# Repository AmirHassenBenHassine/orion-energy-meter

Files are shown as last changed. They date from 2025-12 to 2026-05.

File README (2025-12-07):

 # Orion Energy Monitor

A three-phase energy monitoring system built on ESP32 for real-time power consumption tracking and reporting.

## Overview

The Orion Energy Monitor measures voltage and current across three phases, calculates power consumption, and transmits data via MQTT. It supports WiFi provisioning through a captive portal, OTA firmware updates, and battery-powered operation with light sleep for power efficiency.

## Hardware Requirements

- ESP32 development board
- ZMPT101B voltage sensor module
- 3x SCT-013 current transformer sensors 
- Li-ion battery with charging circuit 
- Status LEDs (power, WiFi, charging, battery)
- Push buttons for WiFi pairing and hard reset

## Pin Configuration

| Function | GPIO |
|---|---|
| Voltage Sensor | 32 |
| Current Phase R | 39 |
| Current Phase Y | 34 |
| Current Phase B | 35 |
| Battery Voltage | 36 |
| Power LED | 14 |
| WiFi LED | 27 |
| Charging LED | 26 |
| Battery LED | 25 |
| WiFi Pairing Button | 4 |
| Hard Reset Button | 13 |
| Charging Status | 33 |

## Features

### Energy Monitoring
- Three-phase voltage and current measurement
- Real-time power calculation per phase
- Cumulative energy tracking (kWh)
- Configurable calibration values

### Connectivity
- WiFi with captive portal for initial setup
- MQTT for data transmission
- mDNS service discovery for broker detection
- Automatic reconnection handling

### Power Management
- Light sleep between measurement cycles
- Battery voltage monitoring
- Charging status detection
- LED indicators for system status

### Firmware Updates
- OTA updates from GitHub releases
- ETag-based update detection
- Rollback protection

## Building

### Prerequisites

- PlatformIO CLI or IDE
- ESP32 board support

### Build Commands

```bash
# Build firmware
pio run -e esp32dev

# Upload to device
pio run -t upload -e esp32dev

# Monitor serial output
pio device monitor
```

## Configuration

Edit `include/config.h` to modify:

- `DATA_SEND_INTERVAL_MS` - Interval between measurements (default: 30000ms)
- `MQTT_BROKER_HOST` - MQTT broker hostname
- `MQTT_BROKER_PORT` - MQTT broker port (default: 1883)
- `VOLTAGE_CALIBRATION` - Voltage sensor calibration factor
- `CURRENT_CALIBRATION_DEFAULT` - Current sensor calibration factor

## MQTT Topics

| Topic | Direction | Description |
|---|---|---|
| `energy/metrics` | Publish | JSON payload with energy data |
| `orion/status` | Publish | Device connection status |
| `orion/config` | Subscribe | WiFi credential updates |
| `orion/trigger` | Subscribe | Remote commands |
| `orion/refresh` | Subscribe | Network scan requests |

### Metrics Payload Format

```json
{
  "deviceId": "XXXXXXXXXXXX",
  "battery": 85.5,
  "timestamp": "2025-01-15 14:30:00",
  "voltage": 230.5,
  "totalPower": 1500.0,
  "energyTotal": 12.5,
  "phases": [
    {"current": 2.1, "power": 483.0},
    {"current": 2.3, "power": 529.0},
    {"current": 2.1, "power": 488.0}
  ]
}
```

## WiFi Provisioning

1. Hold the WiFi pairing button during boot
2. Connect to the "OrionSetup" access point
3. Configure WiFi credentials through the captive portal
4. Device will restart and connect to the configured network

## Hard Reset

Hold the hard reset button during boot to erase all stored credentials and settings. The device will restart in provisioning mode.

## MQTT Broker Setup

The device uses mDNS to discover MQTT brokers. For automatic discovery, configure your broker to advertise via mDNS:

### Mosquitto on Linux

Create `/etc/avahi/services/mosquitto.service`:

```xml
<?xml version="1.0" standalone='no'?>
<!DOCTYPE service-group SYSTEM "avahi-service.dtd">
<service-group>
  <name>Mosquitto MQTT Broker</name>
  <service>
    <type>_mqtt._tcp</type>
    <port>1883</port>
  </service>
</service-group>
```

Restart Avahi:

```bash
sudo systemctl restart avahi-daemon
```

## Calibration

### Voltage Calibration

1. Measure actual mains voltage with a multimeter
2. Compare with reported voltage
3. Adjust `VOLTAGE_CALIBRATION` in config.h:
   ```
   new_cal = current_cal * (actual_voltage / reported_voltage)
   ```

### Current Calibration

1. Connect a known load
2. Measure actual current with a clamp meter
3. Adjust `CURRENT_CALIBRATION_DEFAULT` similarly

## Project Structure

```
orion_monitor/
├── include/
│   ├── config.h           # Configuration constants
│   ├── battery_manager.h
│   ├── ble_manager.h
│   ├── button_manager.h
│   ├── energy_sensor.h
│   ├── led_manager.h
│   ├── mqtt_manager.h
│   ├── ota_manager.h
│   ├── utils.h
│   └── wifi_manager.h
├── src/
│   ├── main.cpp           # Application entry point
│   ├── battery_manager.cpp
│   ├── ble_manager.cpp
│   ├── button_manager.cpp
│   ├── energy_sensor.cpp
│   ├── led_manager.cpp
│   ├── mqtt_manager.cpp
│   ├── ota_manager.cpp
│   ├── utils.cpp
│   └── wifi_manager.cpp
├── platformio.ini         # Build configuration
└── README.md
```

## Dependencies

Managed automatically by PlatformIO:

- WiFiManager
- PubSubClient
- ArduinoJson
- EmonLib
- NimBLE-Arduino

## Troubleshooting

### Device not connecting to WiFi
- Verify credentials are correct
- Check signal strength
- Try moving closer to the access point
- Use hard reset to clear stored credentials

### MQTT connection failing
- Verify broker is running and accessible
- Check firewall settings
- Ensure mDNS/Avahi is configured on broker host
- Check broker logs for connection attempts

### Incorrect readings
- Verify sensor connections
- Check calibration values
- Ensure CT sensors are oriented correctly on the wire
- Confirm voltage sensor is connected to live and neutral

### High power consumption
- Reduce `DATA_SEND_INTERVAL_MS` 
- Check for floating GPIO pins

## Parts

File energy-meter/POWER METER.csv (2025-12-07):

Qty | Value | Device | Package | Parts | Description | AVAILABILITY | CHECK_PRICES | COMMENT | CONFIGURATION_POLE-THROW | CONTACT_CURRENT_RATING | DESCRIPTION | MF | MP | MPN | OC_FARNELL | OC_NEWARK | PACKAGE | POPULARITY | PRICE | SNAPEDA_LINK | SPICEMODEL | SPICEPREFIX
2 |  | AK500/2 | AK500/2 | X1, X2 | CONNECTOR |  | https://cothings.net/collections/pins/products/bornier-a-visser-2-poles |  |  |  |  |  |  |  | unknown | unknown |  | 14
2 |  | C-EUC1206K | C1206K | C5, C6 | CAPACITOR, European symbol |  |  |  |  |  |  |  |  |  |  |  |  | 13 |  |  |  | C
4 |  | CPOL-EUE2.5-6 | E2,5-6 | C2, C3, C4, C7 | POLARIZED CAPACITOR, European symbol |  |  |  |  |  |  |  |  |  |  |  |  | 26 |  |  |  | C
4 |  | LEDCHIPLED_1206 | CHIPLED_1206 | CHARGED, CHARGING, POWER, WIFI | LED |  | https://2btrading.tn/afficheurs-led-lcd/5230-diode-led-smd-1206-orange.html |  |  |  |  |  |  |  |  |  |  | 28
6 |  | PINHD-1X1 | 1X01 | JP11, JP14, JP15, JP16, JP17, JP18 | PIN HEADER |  |  |  |  |  |  |  |  |  |  |  |  | 64
1 |  | PINHD-1X4 | 1X04 | JP2 | PIN HEADER |  |  |  |  |  |  |  |  |  |  |  |  | 91
1 |  | PINHD-1X6/90 | 1X06/90 | JP1 | PIN HEADER |  | https://cothings.net/collections/pins/products/barrette-secable-femelle-40pin-2-54mm |  |  |  |  |  |  |  |  |  |  | 10
6 | 634 | RR1206 | R1206 | R7, R8, R9, R10, R13, R14 | RESISTOR, European symbol |  |  |  |  |  |  |  |  |  |  |  |  |  |  |  | NONE | R
1 |  | S02P | S02P | ON/OFF | AMP MT CONNECTOR |  | https://www.celectronix.com/ensembles-c-bles/5455-connecteur-2p-jst-xh-male-2-54mm.html |  |  |  |  |  |  |  | unknown | unknown |  | 0
1 |  | S04P | S04P | SV2 | AMP MT CONNECTOR |  | https://www.celectronix.com/ensembles-c-bles/5453-connecteur-4p-jst-xh-male-2-54mm.html |  |  |  |  |  |  |  | unknown | unknown |  | 0
12 | 10k | RR1206 | R1206 | R1, R2, R3, R4, R5, R6, R11, R12, R15, R16, R17, R18 | RESISTOR, European symbol |  |  |  |  |  |  |  |  |  |  |  |  |  |  |  | NONE | R
4 | 1437566-3 | 1437566-3 | SW_1437566-3 | BOOT, EN, RESET2, RESET3 | Switch Tactile OFF (ON) SPST Rectangular Button Gull Wing 0.05A 12VDC SMD Loose Piece Check availability | In Stock | https://2btrading.tn/commutateurs/6583-bouton-poussoir-3x6x25-flat.html | 1437566-3 | Single Pole - Single Throw | 50 mA | FSMSM=3.5X6 SMT TACT | TE Connectivity 1437566-3 | TE Connectivity | 1437566-3 |  |  |  | None |  | None | https://www.snapeda.com/parts/1437566-3/TE+Connectivity+ALCOSWITCH+Switches/view-part/?ref=snap
1 | AMS1117-3.3 | AMS1117-3.3 | SOT229P700X180-4N | U3 | Check availability | Not in stock | https://cothings.net/products/regulateur-de-tension-ams1117-cms-3-3-v-800-ma |  |  |  | Sot223/Pkg 1-Amp 3.3-Volt Low Drop Out Voltage Regulatator | Advanced Monolithic Systems | AMS1117-3.3 |  |  |  | SOT-223 Seeed Technology |  | None | https://www.snapeda.com/parts/AMS1117-3.3/Advanced+Monolithic+Systems/view-part/?ref=snap
1 | BH-18650-PC | BH-18650-PC | BAT_BH-18650-PC | BT2 | Check availability | In Stock | https://cothings.net/products/support-de-cellule-pour-1x-18650 |  |  |  | Battery Holder (Open) 18650 1 Cell PC Pin | MPD (Memory | BH-18650-PC |  |  |  | None |  | None | https://www.snapeda.com/parts/BH-18650-PC/MPD+%2528Memory+Protection+Devices%2529/view-part/
1 | ESP32-WROOM-32D | ESP32-WROOM-32D | MODULE_ESP32-WROOM-32D | U1 | Bluetooth, WiFi 802.11b/g/n, Bluetooth v4.2 + EDR, Class 1, 2 and 3 Transceiver Module 2.4GHz ~ 2.5GHz Integrated, Trace Surface Mount Check availability | In Stock |  |  |  |  | Bluetooth, WiFi 802.11b/g/n, Bluetooth v4.2 +EDR, Class 1, 2 and 3 Transceiver Module 2.4GHz ~ 2.5GHz Integrated | Espressif Systems | ESP32-WROOM-32D |  |  |  | Non Standard Espressif Systems |  | None | https://www.snapeda.com/parts/ESP32-WROOM-32D/Espressif+Systems/view-part/?ref=snap
3 | SJ2-3573A2-SMT-TR | SJ2-3573A2-SMT-TR | CUI_SJ2-3573A2-SMT-TR | J1, J2, J3 | Check availability | In Stock | https://cothings.net/products/prise-casque-audio-stereo-5-broches-3-5mm-montage-sur-panneau-pcb-pj-324m |  |  |  | 3 conductors, 3.5mm, SMT Audio Jack | Same Sky | SJ2-3573A2-SMT-TR |  |  |  | None |  | None | https://www.snapeda.com/parts/SJ2-3573A2-SMT-TR/Same+Sky/view-part/?ref=snap

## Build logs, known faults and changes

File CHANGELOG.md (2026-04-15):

# Orion Energy Meter — Changelog

All notable changes to the ESP32 energy meter firmware are documented here.
Format follows [Keep a Changelog](https://keepachangelog.com/).

## [1.0.0] — 2026-04-15

### Core Features
- Three-phase energy monitoring (ZMPT101B voltage + 3× SCT-013 current)
- Per-phase NVS-based dynamic calibration with individual R/Y/B values
- Real-time power (W), energy (kWh), and cumulative energy tracking
- CT sensor auto-detection with periodic recheck during operation
- 500-sample RMS voltage measurement for ±1% accuracy

### Connectivity
- WiFi with WPA2 and captive portal provisioning ("OrionSetup" AP)
- MQTT QoS 1 via PubSubClient with mDNS broker auto-discovery
- Automatic MQTT reconnection with exponential backoff
- Smart fallback mode: disables auto-reconnect after prolonged disconnection, switches to manual retry intervals
- WiFi credential updates received over MQTT (orion/config topic)
- mDNS hostname registration as "OrionEM"

### Data Resilience
- NVS-based offline data buffer (672 readings = 1 week at 15-min intervals)
- CompactReading struct (packed binary) for efficient NVS storage
- Automatic buffer flush on MQTT reconnection with progress logging
- Corrupted reading detection and skip during buffer replay
- Ring buffer with separate read/write indices and count metadata

### Power Management
- Light sleep between measurement cycles with configurable duration
- Smart sleep with periodic wake for button checks (CHECK_INTERVAL_MS)
- EXT0 wake on hard reset button, EXT1 wake on WiFi pairing button
- Noise rejection during sleep wake (80% sample threshold over 10 readings)
- Battery voltage monitoring via ADC with 20-sample averaging
- TP4056 charging status detection via GPIO 33
- LED indicators for power, WiFi, charging, and battery states

### OTA Updates
- GitHub-based firmware updates from DioneProtocol/orion-firmware
- ETag-based version detection (version.json + firmware.bin)
- SHA-256 checksum verification before installation
- Rollback protection via esp_ota partition validation
- Measurement-aware scheduling: OTA waits for active sensor reads to complete
- Automatic daily check interval (OTA_CHECK_INTERVAL_MS = 86400000)
- Power loss recovery: detects first boot after OTA via partition state

### Hardware Interface
- Button debouncing with multi-sample validation (10 samples, 80% threshold)
- Boot mode detection: normal, WiFi pairing (3s hold), hard reset (5s hold)
- Immediate action callbacks during button press (not just on release)
- LED manager with blink modes: solid on, fast blink, slow blink, off
- Hard reset clears all NVS preferences and restarts in provisioning mode

### Testing
- Embedded Unity test framework with 12 test categories
- Test suites: battery, button, chip, energy, integration, LED, memory, MQTT, OTA, preferences, time, WiFi
- TLS connection tests with Let's Encrypt and ISRG Root X1 CA certs
- OTA corruption and power-loss recovery tests
- ADC stability and calibration accuracy tests

### Security (Prepared, Not Yet Active)
- MqttSecurityConfig struct with TLS, mutual TLS, and auth fields
- WiFiClientSecure setup with CA cert, client cert, and private key slots
- MQTT credential storage and loading via NVS
- Certificate infrastructure in certificates.h (commented, awaiting VPS broker)

### Dependencies
- PlatformIO (espressif32 platform)
- ArduinoJson v7.2.0
- WiFiManager v2.0.17
- PubSubClient v2.8
- EmonLib v1.1.0
- NimBLE-Arduino v2.3.6 (included, BLE not yet active)
- Unity v2.5.2 (test framework)

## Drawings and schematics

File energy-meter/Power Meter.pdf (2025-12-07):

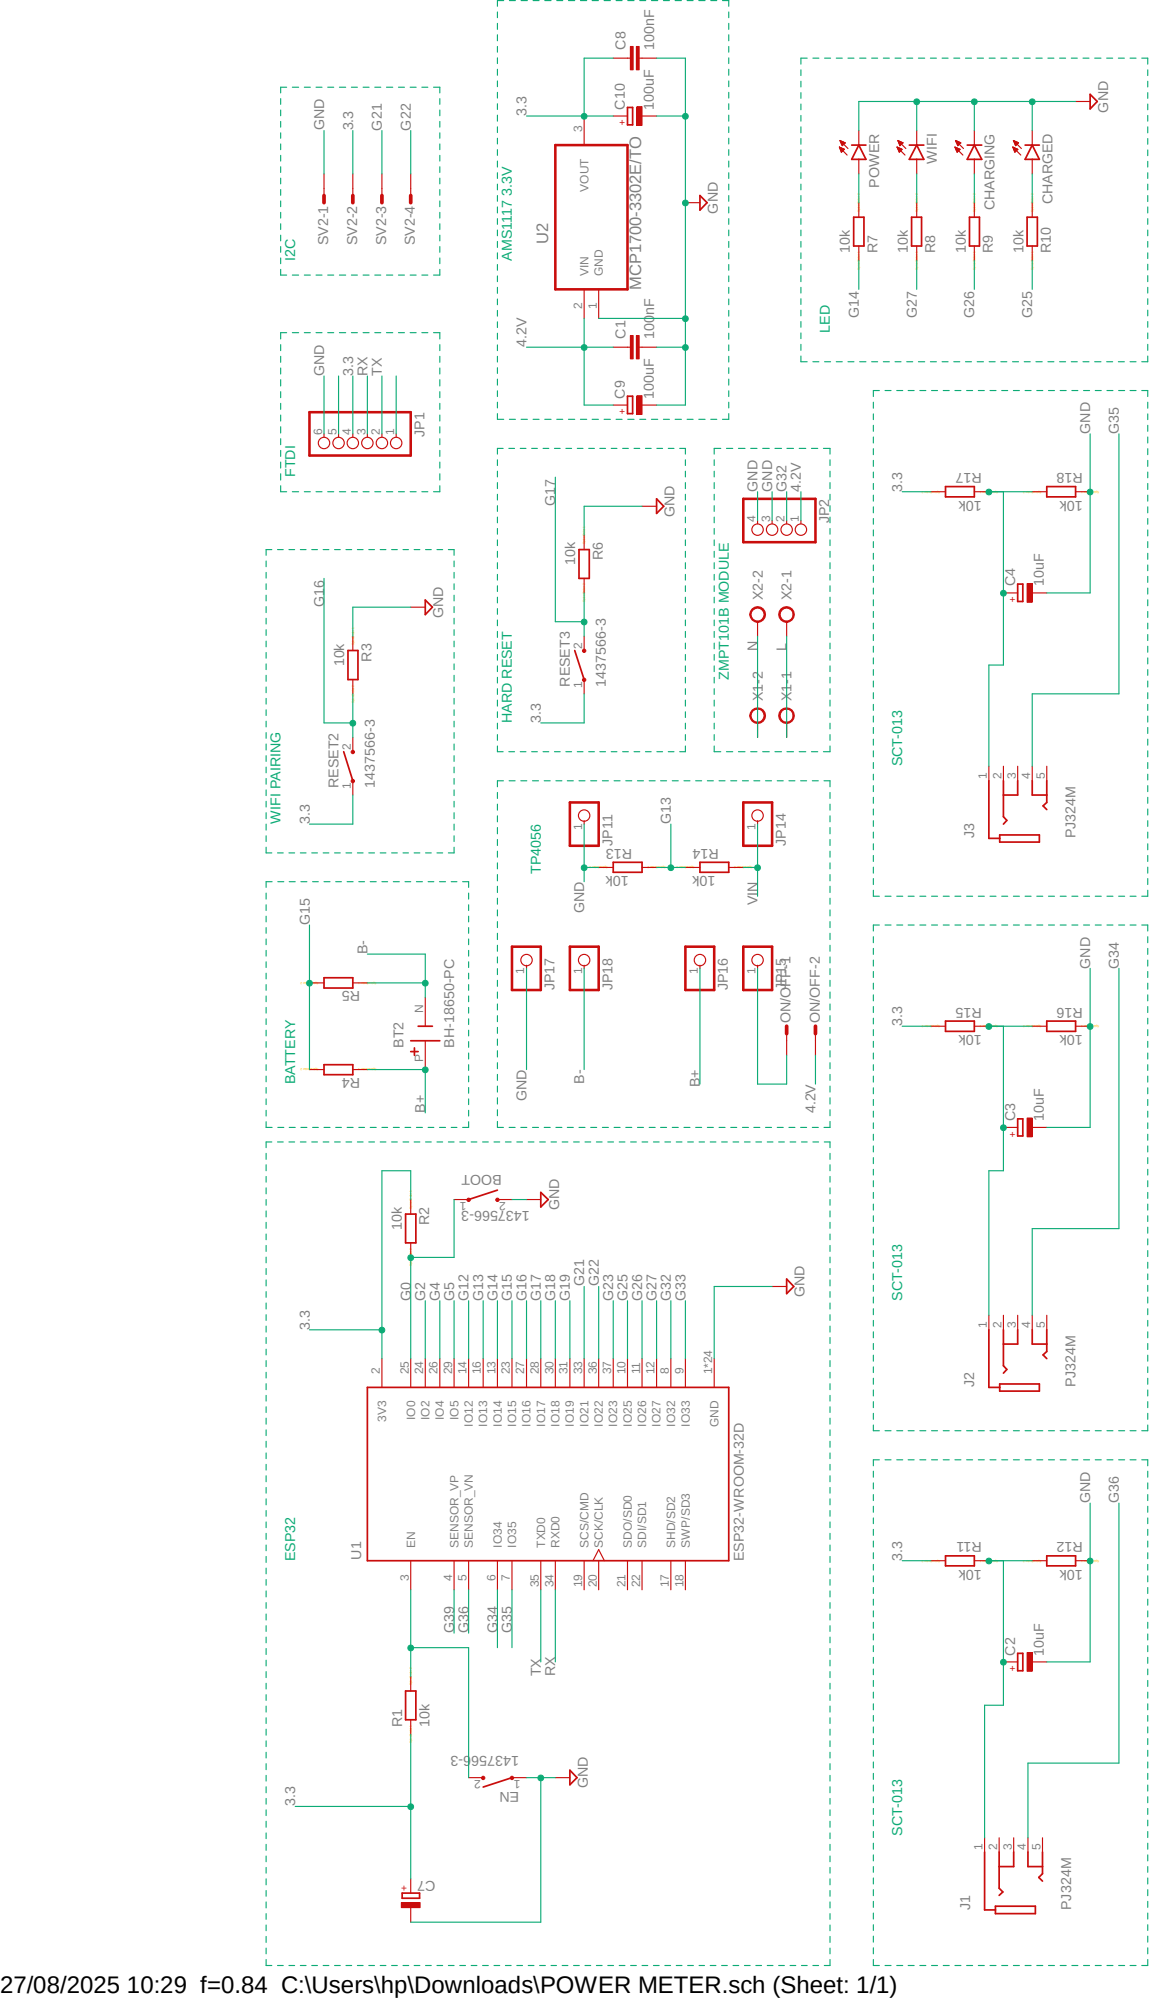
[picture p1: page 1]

5 J3 GND GND GND GND GND GND GND GND GND G22 G22 G21 G21 3.3 3.3 3.3 3.3 3.3 3.3 3.3 3.3 3.3 3.3 G12 G13 G13 TX TX RX RX G2 G4 G5 G14 G14 G15 G15 G16 G16 G17 G17 G18 G19 G23 G25 G25 G26 G26 G27 G27 G32 G32 G33 G35 G35 G34 G34 G39 G0 B+ B+ B- B- VIN 4.2V 4.2V 4.2V N

1 JP151 JP161 JP171 JP18 R4 R5 ON/OFF-1 ON/OFF-2 RESET2 1 2 R3 RESET3 1 2 R6 POWER WIFI CHARGING CHARGED R7 R8 R9 R10 X2-2 X2-1

8 IO25 10 IO26 11 IO27 12 IO14 13 IO12 14 IO13 16 IO15 23 IO2 24 IO0 25 IO4 26 IO16 27 IO17 28 IO5 29 IO18 30 IO19 31 IO21 33 IO22 36 IO23 37 RXD0 34 TXD0 35 SHD/SD2 17 SWP/SD3 18 SCS/CMD 19 SCK/CLK 20 SDO/SD0 21 SDI/SD1 22 U1

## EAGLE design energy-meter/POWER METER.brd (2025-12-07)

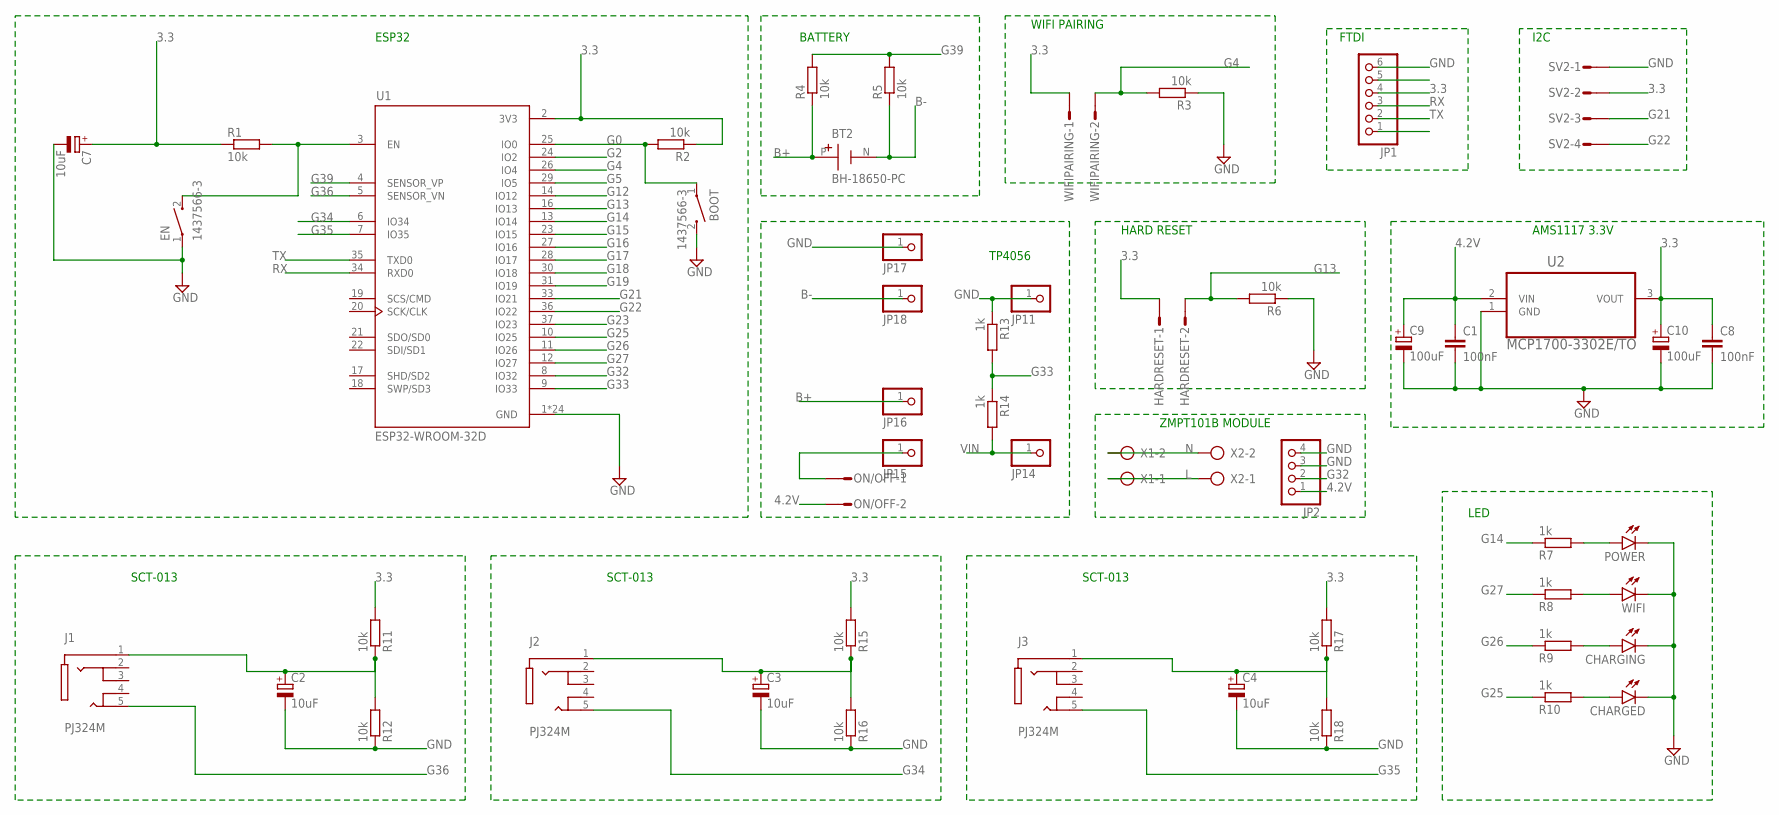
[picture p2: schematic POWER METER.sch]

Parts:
BOOT: 1437566-3; SW_1437566-3
BT2: BH-18650-PC; BAT_BH-18650-PC
C1, C8: 100nF; C1206K
C2, C3, C4, C7: 10uF; E2,5-6
C9, C10: 100uF; E2,5-6
CHARGED: LEDCHIPLED_1206; CHIPLED_1206
CHARGING: LEDCHIPLED_1206; CHIPLED_1206
EN: 1437566-3; SW_1437566-3
HARDRESET: S02P
J1, J2, J3: PJ324M; WENZHOU_PJ324M
JP1: PINHD-1X6/90; 1X06/90
JP2: PINHD-1X4; 1X04
JP11, JP14, JP15, JP16, JP17, JP18: PINHD-1X1; 1X01
ON/OFF: S02P
POWER: LEDCHIPLED_1206; CHIPLED_1206
R1, R2, R3, R4, R5, R6, R11, R12, R15, R16, R17, R18: 10k; R1206
R7, R8, R9, R10, R13, R14: 1k; R1206
SV2: S04P
U1: ESP32-WROOM-32D; MODULE_ESP32-WROOM-32D
U2: MCP1700-3302E/TO; TO127P254X495-3
WIFI: LEDCHIPLED_1206; CHIPLED_1206
WIFIPAIRING: S02P
X1, X2: AK500/2

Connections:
3.3: C7.+, C8.1, C10.+, HARDRESET.1, JP1.4, R1.1, R2.1, R11.2, R15.2, R17.2, SV2.2, U1.2 (3V3), U2.3 (VOUT), WIFIPAIRING.1
4.2V: C1.1, C9.+, JP2.1, ON/OFF.2, U2.2 (VIN)
B+: BT2.P (+), JP16.1, R4.1
B-: BT2.N (-), JP18.1, R5.1
G0: BOOT.1, R2.2, U1.25 (IO0)
G2: U1.24 (IO2)
G4: R3.2, U1.26 (IO4), WIFIPAIRING.2
G5: U1.29 (IO5)
G12: U1.14 (IO12)
G13: HARDRESET.2, R6.2, U1.16 (IO13)
G14: R7.1, U1.13 (IO14)
G15: U1.23 (IO15)
G16: U1.27 (IO16)
G17: U1.28 (IO17)
G18: U1.30 (IO18)
G19: U1.31 (IO19)
G21: SV2.3, U1.33 (IO21)
G22: SV2.4, U1.36 (IO22)
G23: U1.37 (IO23)
G25: R10.1, U1.10 (IO25)
G26: R9.1, U1.11 (IO26)
G27: R8.1, U1.12 (IO27)
G32: JP2.2, U1.8 (IO32)
G33: R13.2, R14.1, U1.9 (IO33)
G34: J2.5 (TIP_2), U1.6 (IO34)
G35: J3.5 (TIP_2), U1.7 (IO35)
G36: J1.5 (TIP_2), U1.5 (SENSOR_VN)
G39: R4.2, R5.2, U1.4 (SENSOR_VP)
GND: BOOT.2, C1.2, C2.-, C3.-, C4.-, C7.-, C8.2, C9.-, C10.-, CHARGED.C, CHARGING.C, EN.1, JP1.6, JP2.3, JP2.4, JP11.1, JP17.1, POWER.C, R3.1, R6.1, R12.1, R13.1, R16.1, R18.1, SV2.1, U1.1 (GND), U1.15 (GND), U1.38 (GND), U1.39_1 (GND), U1.39_2 (GND), U1.39_3 (GND), U1.39_4 (GND), U1.39_5 (GND), U1.39_6 (GND), U1.39_7 (GND), U1.39_8 (GND), U1.39_9 (GND), U1.39_10 (GND), U1.39_11 (GND), U1.39_12 (GND), U1.39_13 (GND), U1.39_14 (GND), U1.39_15 (GND), U1.39_16 (GND), U1.39_17 (GND), U1.39_18 (GND), U1.39_19 (GND), U1.39_20 (GND), U1.39_21 (GND), U2.1 (GND), WIFI.C
L: X1.1, X2.1
N: X1.2, X2.2
unnamed: EN.2, R1.2, U1.3 (EN)
unnamed: POWER.A, R7.2
unnamed: JP15.1, ON/OFF.1
unnamed: R8.2, WIFI.A
unnamed: CHARGING.A, R9.2
unnamed: CHARGED.A, R10.2
unnamed: C2.+, J1.1 (SLEEVE), R11.1, R12.2
unnamed: C4.+, J3.1 (SLEEVE), R17.1, R18.2
unnamed: C3.+, J2.1 (SLEEVE), R15.1, R16.2
RX: JP1.3, U1.34 (RXD0)
TX: JP1.2, U1.35 (TXD0)
VIN: JP14.1, R14.2

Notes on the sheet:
ESP32
TP4056
BATTERY
WIFI PAIRING
HARD RESET
ZMPT101B MODULE
SCT-013
LED
FTDI
I2C
AMS1117 3.3V

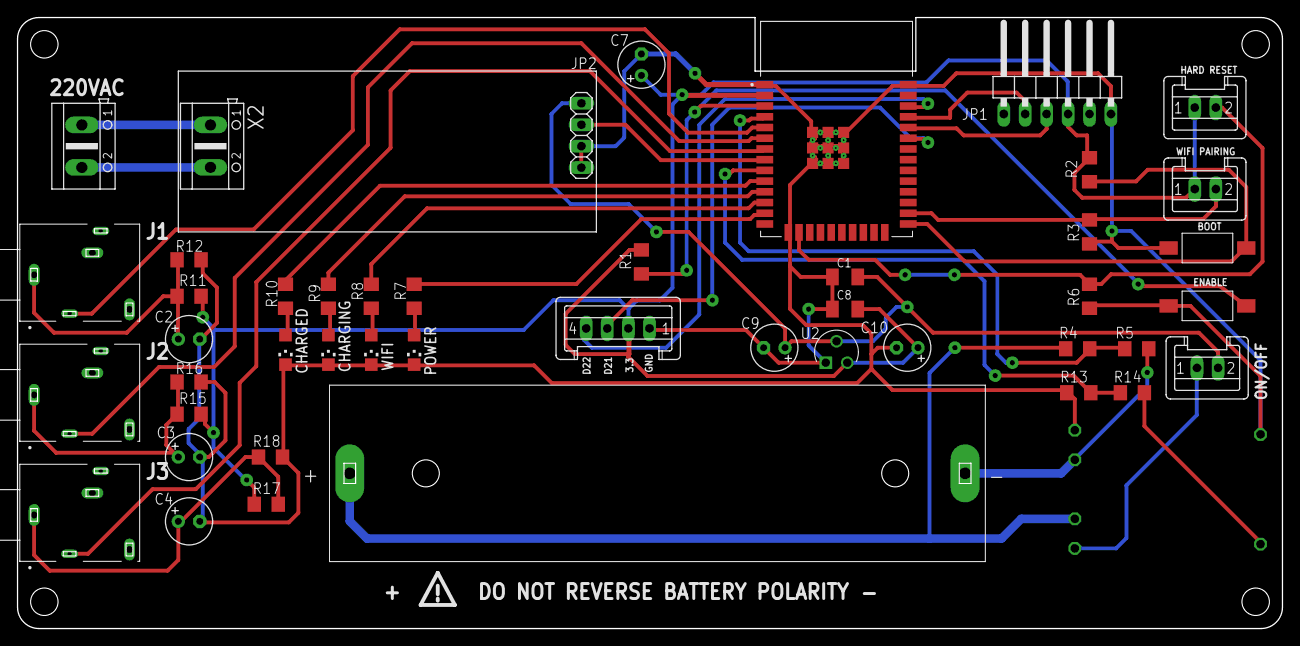
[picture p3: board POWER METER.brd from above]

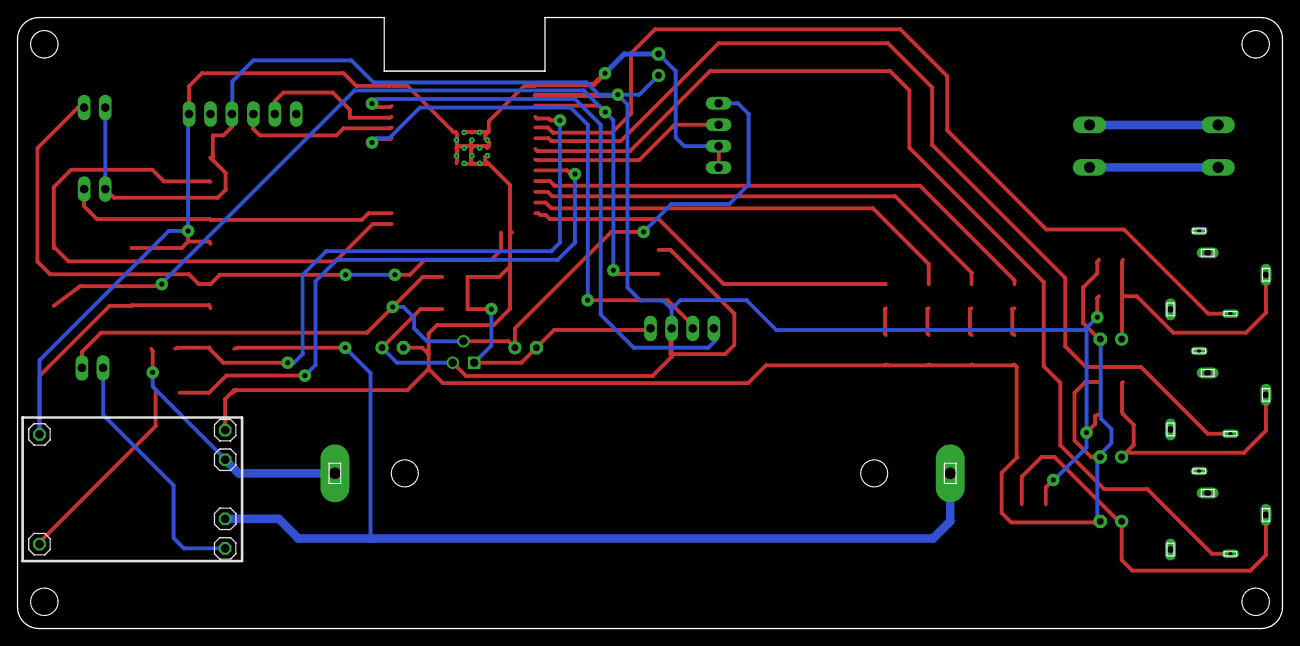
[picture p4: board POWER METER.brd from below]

Board: 2 copper layers, 149.9 x 72.4 mm, 52 parts (6 on the bottom side), 34 nets.

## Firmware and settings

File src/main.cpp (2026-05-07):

#include <Arduino.h>

#include "battery_manager.h"
#include "button_manager.h"
#include "certificates.h"
#include "config.h"
#include "energy_sensor.h"
#include "led_manager.h"
#include "mqtt_manager.h"
#include "ota_manager.h"
#include "utils.h"
#include "wifi_manager.h"
#include <driver/rtc_io.h>
#include <esp_sleep.h>
#include <Preferences.h>

#define MAX_BUFFERED_READINGS 672  // 1 week at 15-min intervals
#define BUFFER_NAMESPACE "data_buf"

// Global device ID
String DEVICE_ID;

RTC_DATA_ATTR uint32_t bootCount = 0;
RTC_DATA_ATTR uint64_t savedRunTime = 0;

static uint64_t lastDataSendTime = 0;
static uint64_t lastTriggerCheck = 0;
static uint64_t lastOtaCheck = 0;
// for sleep mode
static bool inSleepMode = false;
static bool sleepEnabled = true;
static uint64_t sleepStartTime = 0;
static uint64_t totalSleepDuration = 0;
static uint64_t sleepElapsed = 0;

// Current metrics
static EnergySensor::EnergyMetrics currentMetrics;

void handleBootMode(ButtonManager::BootMode mode);
// void handleTriggers();
void sendData();
void enterSmartLightSleep();
void setupMQTT();

struct __attribute__((packed)) CompactReading {
  uint32_t timestampUnix; 
  float voltage;          
  float totalPower;        
  float energyTotal;       
  float current[3];        
  float power[3];         
  uint8_t batteryPercent; 
  uint8_t reserved;        
};

// Buffer metadata
struct BufferMeta {
  uint16_t writeIndex;     // Where to write next
  uint16_t readIndex;      // Where to read next
  uint16_t count;          // How many readings stored
};

// Convert EnergyMetrics to compact format
CompactReading metricsToCompact(const EnergySensor::EnergyMetrics& metrics) {
  CompactReading compact;
  struct tm timeinfo;
    if (getLocalTime(&timeinfo)) {
      compact.timestampUnix = mktime(&timeinfo);
    } else {
      compact.timestampUnix = millis() / 1000; // Fallback to uptime in seconds
    }  
  compact.voltage = metrics.voltage;
  compact.totalPower = metrics.totalPower;
  compact.energyTotal = metrics.energyTotal;
  // Copy current and power arrays directly
  for (int i = 0; i < 3; i++) {
    compact.current[i] = metrics.current[i];
    compact.power[i] = metrics.power[i];
  }
  
  compact.batteryPercent = (uint8_t)metrics.battery;
  compact.reserved = 0;
  
  return compact;
}

// Convert compact back to JSON for MQTT
String compactToJson(const CompactReading& compact) {
  StaticJsonDocument<768> doc;
  
  doc["deviceId"] = DEVICE_ID;
  
  time_t rawtime = compact.timestampUnix;
  struct tm* timeinfo = localtime(&rawtime);
  char timeStr[32];
  strftime(timeStr, sizeof(timeStr), "%Y-%m-%d %H:%M:%S", timeinfo);
  doc["timestamp"] = timeStr;
  
  doc["battery"] = compact.batteryPercent;
  doc["voltage"] = compact.voltage;
  doc["totalPower"] = compact.totalPower;
  doc["energyTotal"] = compact.energyTotal;
  
  // Determine connected phases from data
  // If power is exactly 0 and current is exactly 0, phase is disconnected
  JsonArray connected = doc.createNestedArray("connectedPhases");
  int phaseCount = 0;
  for (int i = 0; i < 3; i++) {
    bool conn = (compact.current[i] > 0.0f || compact.power[i] > 0.0f);
    connected.add(conn);
    if (conn) phaseCount++;
  }
  doc["phaseCount"] = phaseCount;
  
  JsonArray phases = doc.createNestedArray("phases");
  for (int i = 0; i < 3; i++) {
    JsonObject phase = phases.createNestedObject();
    phase["current"] = compact.current[i];
    phase["power"] = compact.power[i];
  }
  
  String output;
  serializeJson(doc, output);
  return output;
}

// Load buffer metadata
BufferMeta loadBufferMeta() {
  Preferences prefs;
  BufferMeta meta = {0, 0, 0};
  
  if (prefs.begin(BUFFER_NAMESPACE, true)) {  // Read-only
    meta.writeIndex = prefs.getUShort("wIdx", 0);
    meta.readIndex = prefs.getUShort("rIdx", 0);
    meta.count = prefs.getUShort("count", 0);
    prefs.end();
  }
  
  return meta;
}

// Save buffer metadata
void saveBufferMeta(const BufferMeta& meta) {
  Preferences prefs;
  if (prefs.begin(BUFFER_NAMESPACE, false)) {  // Read-write
    prefs.putUShort("wIdx", meta.writeIndex);
    prefs.putUShort("rIdx", meta.readIndex);
    prefs.putUShort("count", meta.count);
    prefs.end();
  }
}

// Buffer a reading
void bufferReading(const EnergySensor::EnergyMetrics& metrics) {
  BufferMeta meta = loadBufferMeta();
  
  // Convert to compact format
  CompactReading compact = metricsToCompact(metrics);
  
  Preferences prefs;
  if (!prefs.begin(BUFFER_NAMESPACE, false)) {
    Utils::logMessage("MAIN", "❌ Failed to open buffer storage");
    return;
  }
  
  // Store reading as binary blob
  String key = "d" + String(meta.writeIndex);
  size_t written = prefs.putBytes(key.c_str(), &compact, sizeof(CompactReading));
  prefs.end();
  
  if (written != sizeof(CompactReading)) {
    Utils::logMessage("MAIN", "❌ Failed to write reading");
    return;
  }
  
  // Update metadata
  meta.writeIndex = (meta.writeIndex + 1) % MAX_BUFFERED_READINGS;
  
  if (meta.count < MAX_BUFFERED_READINGS) {
    meta.count++;
  } else {
    // Buffer full - overwrite oldest
    meta.readIndex = (meta.readIndex + 1) % MAX_BUFFERED_READINGS;
    Utils::logMessage("MAIN", "⚠️ Buffer full - overwriting oldest");
  }
  
  saveBufferMeta(meta);
  
  Utils::logMessageF("MAIN", "📦 Buffered reading %d/%d (index %d)", 
                    meta.count, MAX_BUFFERED_READINGS, meta.writeIndex - 1);
}

// Send all buffered data
void sendBufferedData() {
  BufferMeta meta = loadBufferMeta();
  
  if (meta.count == 0) {
    return;
  }
  
  Utils::logMessageF("MAIN", "📤 Sending %d buffered readings...", meta.count);
  
  Preferences prefs;
  if (!prefs.begin(BUFFER_NAMESPACE, false)) {
    Utils::logMessage("MAIN", "❌ Failed to open buffer storage");
    return;
  }
  
  uint16_t sent = 0;
  uint16_t failed = 0;
  
  while (meta.count > 0 && failed < 3) {  // Stop after 3 consecutive failures
    String key = "d" + String(meta.readIndex);
    CompactReading compact;
    
    size_t len = prefs.getBytes(key.c_str(), &compact, sizeof(CompactReading));
    
    if (len == sizeof(CompactReading)) {
      // Convert to JSON and publish
      String json = compactToJson(compact);
      bool success = MqttManager::publish(MQTT_TOPIC_ENERGY_METRICS, json.c_str(), false, 0);
      
      if (success) {
        sent++;
        failed = 0;  // Reset failure counter
        
        // Remove the reading
        prefs.remove(key.c_str());
        
        // Update metadata
        meta.readIndex = (meta.readIndex + 1) % MAX_BUFFERED_READINGS;
        meta.count--;
        
        // Progress indicator every 10 readings
        if (sent % 10 == 0) {
          Utils::logMessageF("MAIN", "  Progress: %d/%d sent", sent, sent + meta.count);
        }
        
        delay(100);  // Small delay between messages to avoid overwhelming broker
      } else {
        failed++;
        Utils::logMessageF("MAIN", "⚠️ Failed to send reading (attempt %d/3)", failed);
        delay(1000);  // Wait before retry
      }
    } else {
      // Corrupted reading - skip it
      Utils::logMessageF("MAIN", "⚠️ Corrupted reading at index %d - skipping", meta.readIndex);
      prefs.remove(key.c_str());
      meta.readIndex = (meta.readIndex + 1) % MAX_BUFFERED_READINGS;
      meta.count--;
    }
  }
  
  prefs.end();
  
  // Save updated metadata
  saveBufferMeta(meta);
  
  Utils::logMessageF("MAIN", "✅ Sent %d buffered readings (%d remaining)", sent, meta.count);
}

// Clear all buffered data (for reset/debug)
void clearBuffer() {
  Preferences prefs;
  if (prefs.begin(BUFFER_NAMESPACE, false)) {
    prefs.clear();
    prefs.end();
    Utils::logMessage("MAIN", "🗑️ Buffer cleared");
  }
}

// Get buffer stats
void printBufferStats() {
  BufferMeta meta = loadBufferMeta();
  float usagePercent = (meta.count * 100.0) / MAX_BUFFERED_READINGS;
  Utils::logMessageF("MAIN", "📊 Buffer: %d/%d readings (%.1f%%)", 
                    meta.count, MAX_BUFFERED_READINGS, usagePercent);
}

// FOR FUTURE WITH VPS BROKER
//  void setupSecureMQTT();

void setup() {
  Serial.begin(115200);
  delay(500);

  Serial.println("ORION ENERGY MONITOR");
  Serial.printf("Version: %s\n", FIRMWARE_VERSION);

  // ✅ Disable watchdog timer
  // disableCore0WDT();
  // disableCore1WDT();
  // Increment boot counter
  bootCount++;
  Utils::logMessageF("MAIN", "Boot count: %lu", bootCount);

  // Generate device ID
  DEVICE_ID = Utils::generateDeviceId();
  Utils::logMessageF("MAIN", "Device ID: %s", DEVICE_ID.c_str());

  Utils::logMessage("MAIN", "Step 1: Initializing hardware...");

  LedManager::begin();
  ButtonManager::begin();
  BatteryManager::begin();
  BatteryManager::update();
  EnergySensor::begin();

  //Register button callback ONCE
  ButtonManager::setImmediateActionCallback([](ButtonManager::ButtonId button, uint32_t duration) -> bool {
  //Don't process buttons during sleep mode
  if (inSleepMode) {
    return false;  // Ignore all button events during sleep
  }

  if (button == ButtonManager::BTN_WIFI_PAIRING && 
      duration >= 3000 && duration < 5000) {
    Utils::logMessage("MAIN", "⚡ Starting WiFi pairing...");
    WifiManager::startPortal(true);  // ✅ Pass true = button triggered
    return true;
  }
  
  if (button == ButtonManager::BTN_HARD_RESET && duration >= 5000) {
    Utils::logMessage("MAIN", "⚡ Performing hard reset...");
    ButtonManager::performHardReset();
    return true;
  }
  
  return false;
});

  Utils::logMessage("MAIN", "Step 2: Checking boot mode...");

  ButtonManager::BootMode bootMode = ButtonManager::detectBootMode();

  // Handle special boot modes
  handleBootMode(bootMode);
  
  Utils::logMessage("MAIN", "Step 3: Initializing  MQTT...");
  // Initialize MQTT
  setupMQTT();

  Utils::logMessage("MAIN", "Step 4: Connecting to WiFi...");
  // Initialize WiFi
  bool forcePortal = (bootMode == ButtonManager::BOOT_WIFI_PAIR);
  WifiManager::begin(forcePortal);

  if (!forcePortal) {
    Utils::logMessage("MAIN", "Waiting for WiFi connection...");
    uint32_t wifiWaitStart = millis();
    while (!WifiManager::isFullyConnected() &&
           (millis() - wifiWaitStart) < 30000) {
      Utils::delayTask(500);
      yield();

    }

    if (WifiManager::isFullyConnected()) {
      Utils::logMessage("MAIN", "WiFi connected!");
    } else {
      Utils::logMessage("MAIN", "WiFi connection timeout, continuing anyway...");
      // ✅ Skip MQTT setup and sensor reading
      lastDataSendTime = Utils::millis64();
      lastTriggerCheck = Utils::millis64();
      lastOtaCheck = Utils::millis64();
      
      Utils::logMessage("MAIN", "SYSTEM READY (AP Mode - No Network)");
      return;  // ✅ Exit setup early
    }
  } else {
    // Portal mode - wait for configuration
    Utils::logMessage("MAIN", "Waiting for WiFi configuration via portal...");
    
    while (WifiManager::getState() == WifiManager::WIFI_STATE_PORTAL_ACTIVE ||
           WifiManager::getState() == WifiManager::WIFI_STATE_AP_MODE) {
      // ✅ Process MQTT while waiting
      MqttManager::loop();
      vTaskDelay(pdMS_TO_TICKS(1000));
      yield();
    }
    
    if (!WifiManager::isFullyConnected()) {
      Utils::logMessage("MAIN", "Portal closed without connection. Restarting...");
      vTaskDelay(pdMS_TO_TICKS(2000));
      ESP.restart();
    }
  }

  Utils::logMessage("MAIN", "Step 5: Initializing OTA...");

  OtaManager::begin();

  if (WifiManager::isFullyConnected()) {
      Utils::logMessage("MAIN", "Checking for updates...");
      
      OtaManager::OtaUpdateInfo info;
      if (OtaManager::checkForUpdate(&info)) {
          Utils::logMessageF("MAIN", "✅ Update available: %s -> %s", 
                            info.currentVersion.c_str(), 
                            info.newVersion.c_str());
          Utils::logMessage("MAIN", "Starting update in 3 seconds...");
          delay(3000);
          OtaManager::performUpdate();
      } else {
          Utils::logMessage("MAIN", "No updates available");
          Utils::logMessageF("MAIN", "Current: %s, Latest: %s", 
                            FIRMWARE_VERSION, 
                            info.newVersion.c_str());
      }
  }

  lastDataSendTime = Utils::millis64();
  lastTriggerCheck = Utils::millis64();
  lastOtaCheck = Utils::millis64();

  Serial.println("SYSTEM READY");
}

/**
 * Configure and initialize MQTT connection
 */
void setupMQTT() {
  // Initialize with broker config
  MqttManager::begin();

  // Set callbacks
  MqttManager::setConnectionCallback([](MqttManager::MqttState state) {
    switch (state) {
    case MqttManager::MQTT_STATE_CONNECTED:
      Utils::logMessage("MQTT", "MQTT connected");
      break;
    case MqttManager::MQTT_STATE_DISCONNECTED:
      Utils::logMessage("MQTT", "MQTT disconnected");
      break;
    case MqttManager::MQTT_STATE_TLS_ERROR:
    case MqttManager::MQTT_STATE_AUTH_ERROR:
      Utils::logMessage("MQTT", "MQTT error");
      break;
    default:
      break;
    }
  });
}

// XXXXXXXXXXXXXXXXXXXXXX-XXXXXXXXXXXXXXXXXXXX-XXXXXXXXXXXXXX
// FOR FUTURE WITH VPS BROKER
// void setupSecureMQTT() {
//   // Configure security settings
//   MqttManager::MqttSecurityConfig security;
//   security.useTLS = MQTT_USE_TLS;
//   security.verifyServer = MQTT_VERIFY_CERTIFICATE;
//   security.useClientCert = false;
//   security.caCert = MQTT_CA_CERT;
//   security.clientCert = nullptr;
//   security.clientKey = nullptr;
//   security.username = MQTT_DEFAULT_USERNAME;
//   security.password = MQTT_DEFAULT_PASSWORD;
//
//   MqttManager::MqttBrokerConfig broker;
//   broker.host = MQTT_BROKER_HOST;
//   broker.port = MQTT_BROKER_PORT;
//   broker.clientIdPrefix = MQTT_CLIENT_ID_PREFIX;
//   broker.keepAlive = MQTT_KEEPALIVE_SEC;
//   broker.bufferSize = MQTT_BUFFER_SIZE;
//   broker.qos = MQTT_QOS_DEFAULT;
//   broker.cleanSession = true;
//
//   // Apply security configuration
//   MqttManager::configureSecurity(security);
//
//   // Initialize with broker config
//   MqttManager::begin(broker);
//
//   // Set callbacks
//   MqttManager::setConnectionCallback([](MqttManager::MqttState state) {
//     switch (state) {
//     case MqttManager::MQTT_STATE_CONNECTED:
//       LedManager::setMode(LedManager::LED_WIFI, LedManager::LED_ON);
//       break;
//     case MqttManager::MQTT_STATE_DISCONNECTED:
//       LedManager::setMode(LedManager::LED_WIFI, LedManager::LED_BLINK_SLOW);
//       break;
//     case MqttManager::MQTT_STATE_TLS_ERROR:
//     case MqttManager::MQTT_STATE_AUTH_ERROR:
//       LedManager::setMode(LedManager::LED_WIFI, LedManager::LED_BLINK_FAST);
//       break;
//     default:
//       break;
//     }
//   });
// }
// XXXXXXXXXXXXXXXXXXXXXX-XXXXXXXXXXXXXXXXXXXX-XXXXXXXXXXXXXXo

void takeEnergyMeasurement() {
    // ✅ Tell OTA manager that measurement is starting
    OtaManager::setMeasurementActive(true);
    
    // Your existing measurement code
    EnergySensor::readSensors(currentMetrics);
    
    // ✅ Tell OTA manager that measurement is complete
    OtaManager::setMeasurementActive(false);
}

void loop() {
  uint64_t now = Utils::millis64();
  yield();

  // static bool otaValidated = false;
  // if (!otaValidated && millis() > 30000) {
  //   OtaManager::markFirmwareValid();
  //   otaValidated = true;
  //   Utils::logMessage("MAIN", "OTA firmware marked as valid");
  // }

  if (WifiManager::isPortalActive()) {
    Utils::delayTask(1000);
    return;
  }

  if (!WifiManager::isFullyConnected()) {
    Utils::delayTask(1000);
    return;
  }

  //MQTT reconnection with fallback mode
  static uint32_t mqttDisconnectedAt = 0;
  static bool mqttInFallbackMode = false;
  static uint32_t lastFallbackRetry = 0;
  static bool mqttStateResolved = false; 
  
  if (!MqttManager::isConnected()) {
    // Track when disconnection started
    if (mqttDisconnectedAt == 0) {
      mqttDisconnectedAt = millis();
    }
    
    // After 2 minutes, enter fallback mode
    const uint32_t FALLBACK_THRESHOLD = 60000;  // 1 minute
    if (!mqttInFallbackMode && (millis() - mqttDisconnectedAt) > FALLBACK_THRESHOLD) {
      Utils::logMessage("MAIN", "⚠️ MQTT unavailable for 2+ minutes");
      Utils::logMessage("MAIN", "Entering fallback mode - will retry every 5 minutes");
      mqttInFallbackMode = true;
      mqttStateResolved = true; 
      lastFallbackRetry = millis();
      
      MqttManager::setAutoReconnect(false);
      MqttManager::disconnect();
    }
    
    // In fallback mode, retry every 5 minutes
    if (mqttInFallbackMode) {
      const uint32_t FALLBACK_RETRY = 300000;  // 5 minutes
      
      if (millis() - lastFallbackRetry > FALLBACK_RETRY) {
        Utils::logMessage("MAIN", "🔄 Fallback retry: Testing MQTT connection...");
        lastFallbackRetry = millis();
        
        MqttManager::setAutoReconnect(true);
        MqttManager::reconnect();
        
        uint32_t retryStart = millis();
        while (!MqttManager::isConnected() && (millis() - retryStart) < 20000) {
          MqttManager::loop();
          delay(500);
          yield();
        }
        
        if (!MqttManager::isConnected()) {
          Utils::logMessage("MAIN", "Retry failed - continuing in fallback mode");
          MqttManager::setAutoReconnect(false);
          MqttManager::disconnect();
        } else {
          Utils::logMessage("MAIN", "✅ Retry succeeded!");
        }
      }
    } else {
      // NOT in fallback mode yet - let MQTT try its internal reconnection
      MqttManager::loop();
    }
  } else {
    // Connected! Reset everything
    if (mqttDisconnectedAt > 0) {
      uint32_t downtime = (millis() - mqttDisconnectedAt) / 1000;
      mqttDisconnectedAt = 0;
      mqttInFallbackMode = false;
      MqttManager::setAutoReconnect(true);
    }
    
    mqttStateResolved = true;  
    MqttManager::loop();
  }

  if (!mqttStateResolved) {
    Utils::delayTask(1000);
    return; 
  }

  OtaManager::loop();
  
  // if (MqttManager::isConnected() && now - lastTriggerCheck >= TRIGGER_CHECK_INTERVAL_MS) {
  //   handleTriggers();
  //   lastTriggerCheck = now;
  // }

  if (now - lastDataSendTime >= DATA_SEND_INTERVAL_MS) {
    Utils::logMessage("MAIN", "Sensor reading interval reached");

    BatteryManager::update();
    takeEnergyMeasurement();
    EnergySensor::printMetrics(currentMetrics);
    sendData();
    lastDataSendTime = now;

    // if (MqttManager::isConnected()) {
    //   handleTriggers();
    // }

    OtaManager::loop();
    delay(100);
    
    // ✅ CORRECT - Use namespace prefix
    OtaManager::OtaState otaState = OtaManager::getState();
    if (otaState == OtaManager::OTA_STATE_DOWNLOADING || 
        otaState == OtaManager::OTA_STATE_INSTALLING || 
        otaState == OtaManager::OTA_STATE_VERIFYING) {
        // OTA in progress - skip sleep
        Utils::logMessage("MAIN", "⏭ Skipping sleep (OTA in progress)");
        return;
    }
    else {
        Utils::logMessage("MAIN", "No updates in progress");

    }

    Utils::logMessageF("MAIN", "Sleep check: enabled=%d, pairingMode=%d, portalActive=%d, mqttFailed=%d", 
                      sleepEnabled ? 1 : 0, 
                      WifiManager::isInPairingMode() ? 1 : 0,
                      WifiManager::isPortalActive() ? 1 : 0,
                      mqttInFallbackMode ? 1 : 0);

    if (sleepEnabled && !WifiManager::isInPairingMode() && !WifiManager::isPortalActive()) {
        enterSmartLightSleep();
    } else {
      Utils::logMessage("MAIN", "⏭ Skipping sleep (conditions not met)");
    }
  }

  if (MqttManager::isConnected() && OtaManager::shouldCheckNow(lastOtaCheck)) {
    Utils::logMessage("MAIN", "Scheduled OTA check");
    if (OtaManager::checkForUpdate()) {
      OtaManager::performUpdate();
    }
    lastOtaCheck = now;
  }
  
  Utils::delayTask(100);
}

void handleBootMode(ButtonManager::BootMode mode) {
  switch (mode) {
  case ButtonManager::BOOT_HARD_RESET:
    Utils::logMessage("MAIN", "HARD RESET requested!");
    ButtonManager::performHardReset();
    break;

  case ButtonManager::BOOT_WIFI_PAIR:
    Utils::logMessage("MAIN", "Entering WiFi pairing mode...");
    WifiManager::startPortal(true);
    break;

  case ButtonManager::BOOT_NORMAL:
  default:
    break;
  }
}

// void handleTriggers() {
//   if (!MqttManager::hasPendingTrigger()) {
//     return;
//   }

//   String action = MqttManager::getPendingTrigger();
//   Utils::logMessageF("MAIN", "Processing trigger: %s", action.c_str());

//   if (action == "reset") {
//     Utils::logMessage("MAIN", "Trigger: Reset WiFi credentials");
//     WifiManager::resetCredentials();
//   } else if (action == "config") {
//     Utils::logMessage("MAIN", "Trigger: Enter WiFi config mode");
//     WifiManager::startPortal(true);
//   } else if (action == "reboot") {
//     Utils::logMessage("MAIN", "Trigger: Reboot device");
//     Utils::delayTask(500);
//     ESP.restart();
//   } else if (action == "ota") {
//     Utils::logMessage("MAIN", "Trigger: Force OTA check");
//     if (OtaManager::checkForUpdate()) {
//       OtaManager::performUpdate();
//     }
//   }
//   // configurable sleep options added in case in future if we need something
//   // like this
//   else if (action == "sleep_on") {
//     sleepEnabled = true;
//     Utils::logMessage("MAIN", "Sleep enabled");
//   } else if (action == "sleep_off") {
//     sleepEnabled = false;
//     Utils::logMessage("MAIN", "Sleep disabled");
//   }

//   MqttManager::clearPendingTrigger();
// }
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

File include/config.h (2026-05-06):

#ifndef CONFIG_H
#define CONFIG_H

#include <Arduino.h>

// DEVICE IDENTIFICATION
#define DEVICE_NAME "Orion Energy Monitor"

#define COMPANY_NAME "Dione Protocol LLC"
#define PRODUCT_NAME "Energy Monitor"

// Device ID will be set dynamically from MAC address
extern String DEVICE_ID;

// PIN DEFINITIONS - SENSORS
#define MAX_PHASES 3
#define VOLTAGE_PIN 32
#define CURRENT_PIN_R 39
#define CURRENT_PIN_Y 34
#define CURRENT_PIN_B 35

// PIN DEFINITIONS - LEDs
#define POWER_LED_PIN 14    // Power status - always on
#define WIFI_LED_PIN 27     // WiFi status
#define CHARGING_LED_PIN 26 // Charging status
#define BATTERY_LED_PIN 25  // Battery status

// PIN DEFINITIONS - BUTTONS
#define WIFI_PAIRING_BTN 4
#define HARD_RESET_BTN 13

// PIN DEFINITIONS - BATTERY
#define CHARGING_STATUS_PIN 33
#define BATTERY_VOLTAGE_PIN 36

// TIMING CONSTANTS
#define DATA_SEND_INTERVAL_MS 30000      // 30 seconds
#define TRIGGER_CHECK_INTERVAL_MS 60000  // 1 minute
#define WAKEUP_TIME_MS 900000            // 15 minute=900000
#define OTA_CHECK_INTERVAL_MS 86400000   // 24 hours

// LED TIMING
#define LED_BLINK_FAST_MS 200
#define LED_BLINK_SLOW_MS 500
#define LED_BLINK_AP_MS 1000

// WIFI CONFIGURATION
#define WIFI_CONFIG_PORTAL_SSID "OrionSetup"
#define WIFI_CONFIG_PORTAL_PASSWORD "Orion2025"
#define WIFI_CONNECT_TIMEOUT_SECONDS 20
#define WIFI_PORTAL_TIMEOUT_SECONDS 900
#define WIFI_CONNECT_TIMEOUT_MS 30000
#define WIFI_MAX_RECONNECT_ATTEMPTS 10
#define WIFI_RECONNECT_DELAY_MS 5000
#define WIFI_STABLE_CONNECTION_MS 120000
#define WIFI_LWIP_STABILIZATION_MS 2000

// MQTT CONFIGURATION
#define MQTT_BROKER_HOST "orion.local"
// xxxxxxxxxxxxxx IN FUTURE TO BE UPDATE TO SECURE PORT ONCE VPS BROKER IS SETUP
// xxxxxxxxxxxxxx
#define MQTT_BROKER_PORT 1883
#define MQTT_BROKER_PORT_INSECURE 1883

// Security
// // xxxxxxxxxxxxxx IN FUTURE TO BE UPDATE TO SECURE CONNECTION ONCE VPS BROKER
// IS SETUP xxxxxxxxxxxxxx
#define MQTT_USE_TLS false
#define MQTT_VERIFY_CERTIFICATE false

// Authentication
// // xxxxxxxxxxxxxx IN FUTURE TO BE UPDATE TO SECURE CONNECTION ONCE VPS BROKER
// IS SETUP xxxxxxxxxxxxxx
#define MQTT_DEFAULT_USERNAME "orion_device"
#define MQTT_DEFAULT_PASSWORD "123456789"

// Client settings
#define MQTT_CLIENT_ID_PREFIX "OrionEM"
#define MQTT_BUFFER_SIZE 2048
#define MQTT_KEEPALIVE_SEC 60
#define MQTT_RECONNECT_DELAY_MS 5000
#define MQTT_MAX_RECONNECT_ATTEMPTS 10

// QoS
#define MQTT_QOS_DEFAULT 1
#define MQTT_QOS_METRICS 1

// Topics
#define MQTT_TOPIC_ENERGY_METRICS "energy/metrics"
#define MQTT_TOPIC_TRIGGER "orion/trigger"
#define MQTT_TOPIC_REFRESH "orion/refresh"
#define MQTT_TOPIC_CONFIG "orion/config"
#define MQTT_TOPIC_STATUS "orion/status"
#define MQTT_TOPIC_SCAN "orion/scan"
#define MQTT_TOPIC_CONFIRM "orion/confirm"
#define MQTT_TOPIC_WIFI_CREDENTIALS "orion/wifi_credentials"  
#define MQTT_TOPIC_PAIRING_STATUS "pairing/status"            

// BLE CONFIGURATION
#define BLE_DEVICE_NAME "ESP32-Orion"
#define BLE_SERVICE_UUID "4fafc201-1fb5-459e-8fcc-c5c9c331914b"
#define BLE_CHARACTERISTIC_UUID "beb5483e-36e1-4688-b7f5-ea07361b26a8"

// ENERGY SENSOR CALIBRATION
#define VOLTAGE_CALIBRATION 210.1f //321.17f
#define CURRENT_CALIBRATION_DEFAULT 4.3f
#define CURRENT_NOISE_THRESHOLD 0.1f
#define CURRENT_MAX_READING 100.0f
#define VOLTAGE_NOMINAL_US 120.0f
#define VOLTAGE_NOMINAL_EU 230.0f

// BATTERY CONFIGURATION
#define BATTERY_SAMPLES 20
#define BATTERY_VOLTAGE_DIVIDER_RATIO 2.0f
#define BATTERY_MAX_VOLTAGE 4.2f
#define BATTERY_MIN_VOLTAGE 3.0f
#define BATTERY_LOW_THRESHOLD 20.0f
#define BATTERY_CRITICAL_THRESHOLD 10.0f

// NTP CONFIGURATION
#define NTP_SERVER "pool.ntp.org"
#define NTP_GMT_OFFSET_SEC 3600
#define NTP_DAYLIGHT_OFFSET_SEC 3600

// OTA CONFIGURATION
#define FIRMWARE_URL "https://raw.githubusercontent.com/DioneProtocol/orion-firmware/main/firmware.bin"
#define VERSION_JSON_URL "https://raw.githubusercontent.com/DioneProtocol/orion-firmware/main/version.json"

#define FIRMWARE_VERSION "1.2.0"
#define OTA_CHECK_INTERVAL_MS 86400000 // Check daily (24 hours)

// FREERTOS TASK CONFIGURATION
#define TASK_STACK_SIZE_SMALL 2048
#define TASK_STACK_SIZE_MEDIUM 4096
#define TASK_STACK_SIZE_LARGE 8192

#define TASK_PRIORITY_LOW 1
#define TASK_PRIORITY_MEDIUM 2
#define TASK_PRIORITY_HIGH 3

#define TASK_CORE_0 0
#define TASK_CORE_1 1

// Task names
#define TASK_NAME_WIFI "WiFiTask"
#define TASK_NAME_MQTT "MQTTTask"
#define TASK_NAME_SENSOR "SensorTask"
#define TASK_NAME_LED_POWER "PowerLED"
#define TASK_NAME_LED_WIFI "WiFiLED"
#define TASK_NAME_LED_CHARGING "ChargingLED"
#define TASK_NAME_LED_BATTERY "BatteryLED"

// MDNS CONFIGURATION
#define MDNS_HOSTNAME "OrionEM"

// CONNECTIVITY TEST
#define CONNECTIVITY_TEST_HOST "google.com"
#define CONNECTIVITY_TEST_PORT 80
#define CONNECTIVITY_TEST_TIMEOUT_MS 5000

// PREFERENCES NAMESPACES
#define PREF_NAMESPACE_WIFI "wifiCreds"
#define PREF_NAMESPACE_OTA "ota"
#define PREF_NAMESPACE_DEVICE "device"
#define PREF_NAMESPACE_MQTT "mqtt"
#endif // CONFIG_H

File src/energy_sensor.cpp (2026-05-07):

#include "energy_sensor.h"
#include "battery_manager.h"
#include "config.h"
#include "utils.h"

#include <EmonLib.h>
#include <Preferences.h>

namespace EnergySensor {

static Preferences _calibPrefs;

// Add near the top with other static variables
static bool _ctConnected[MAX_PHASES] = {false, false, false};
static uint32_t _lastCtCheck[MAX_PHASES] = {0, 0, 0};
static const uint32_t CT_CHECK_INTERVAL = 8000; // Check every 5 seconds

// EmonLib instances
static EnergyMonitor _emonCurrent[MAX_PHASES];
static EnergyMonitor _emonVoltage;

// Current pin mapping
static const int _currentPins[MAX_PHASES] = {CURRENT_PIN_R, CURRENT_PIN_Y,
                                             CURRENT_PIN_B};

// Calibration values
static float _voltageCal = VOLTAGE_CALIBRATION;
static float _currentCal[MAX_PHASES] = {CURRENT_CALIBRATION_DEFAULT,
                                        CURRENT_CALIBRATION_DEFAULT,
                                        CURRENT_CALIBRATION_DEFAULT};

// Energy accumulator
static float _accumulatedEnergy = 0;
static uint64_t _lastUpdateTime = 0;

// Last metrics
static EnergyMetrics _lastMetrics;

// Initialized flag
static bool _initialized = false;

// Serial number
static String _serialNumber = "UNCALIBRATED";

// NVS CALIBRATION FUNCTIONS

/**
 * Load calibration data from NVS
 * Returns true if calibration data was found, false if using defaults
 */
static bool loadCalibrationFromNVS() {  
  if (!_calibPrefs.begin("calibration", false)) { // Read-only mode
    Utils::logMessage("SENSOR", "⚠️  Failed to open NVS calibration - using defaults");
    return false;
  }
  
  // Check if calibration exists
  if (!_calibPrefs.isKey("vCal")) {
    Utils::logMessage("SENSOR", "⚠️  No calibration found in NVS - using defaults");
    _calibPrefs.end();
    return false;
  }
  
  // Load voltage calibration
  _voltageCal = _calibPrefs.getFloat("vCal", VOLTAGE_CALIBRATION);
  
  // Load current calibration for each phase
  _currentCal[0] = _calibPrefs.getFloat("iCal0", CURRENT_CALIBRATION_DEFAULT);
  _currentCal[1] = _calibPrefs.getFloat("iCal1", CURRENT_CALIBRATION_DEFAULT);
  _currentCal[2] = _calibPrefs.getFloat("iCal2", CURRENT_CALIBRATION_DEFAULT);
  
  // Load serial number
  _serialNumber = _calibPrefs.getString("serialNum", "UNCALIBRATED");
  
  _calibPrefs.end();
  
  // Log calibration values
  Utils::logMessage("SENSOR", "✅ Calibration loaded from NVS:");
  Utils::logMessageF("SENSOR", "   Serial Number : %s", _serialNumber.c_str());
  Utils::logMessageF("SENSOR", "   Voltage Cal   : %.3f", _voltageCal);
  Utils::logMessageF("SENSOR", "   Current R Cal : %.3f", _currentCal[0]);
  Utils::logMessageF("SENSOR", "   Current Y Cal : %.3f", _currentCal[1]);
  Utils::logMessageF("SENSOR", "   Current B Cal : %.3f", _currentCal[2]);

  return true;
}

/**
 * Get serial number from NVS
 */
String getSerialNumber() {
  return _serialNumber;
}

// JSON implementation for EnergyMetrics
String EnergyMetrics::toJson() const {
  StaticJsonDocument<768> doc;

  doc["deviceId"] = deviceId;
  doc["timestamp"] = timestamp;
  doc["battery"] = battery;
  doc["voltage"] = voltage;
  doc["totalPower"] = totalPower;
  doc["energyTotal"] = energyTotal;

  // Connected phases array — gateway uses this as source of truth
  JsonArray connected = doc.createNestedArray("connectedPhases");
  int phaseCount = 0;
  for (int i = 0; i < MAX_PHASES; i++) {
    bool conn = isPhaseConnected(i);
    connected.add(conn);
    if (conn) phaseCount++;
  }
  doc["phaseCount"] = phaseCount;

  // Only include connected phases in the array
  JsonArray phases = doc.createNestedArray("phases");
  for (int i = 0; i < MAX_PHASES; i++) {
    JsonObject phase = phases.createNestedObject();
    if (isPhaseConnected(i)) {
      phase["current"] = current[i];
      phase["power"] = power[i];
    } else {
      // Explicitly zero — belt and suspenders
      phase["current"] = 0;
      phase["power"] = 0;
    }
  }

  String output;
  serializeJson(doc, output);
  return output;
}

void EnergyMetrics::reset() {
  voltage = 0;
  totalPower = 0;
  energyTotal = 0;
  battery = 0;
  timestamp = "";
  deviceId = "";

  for (int i = 0; i < MAX_PHASES; i++) {
    current[i] = 0;
    power[i] = 0;
  }
}

bool isPhaseConnected(int phase) {
  if (phase >= 0 && phase < MAX_PHASES) {
    return _ctConnected[phase];
  }
  return false;
}
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

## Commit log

2025-12-07 (Add) ota manager
    [POWER METER.brd, POWER METER.csv, POWER METER.sch]
2025-12-16 Fixed the issues in testing and synchronised with Orion Gateway
    [button_manager.cpp, config.h, energy_sensor.cpp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]
2025-12-24 Fixed workflow and device pairing mechanism
    [button_manager.cpp, main.cpp]
2025-12-30 Fixed pairing workflow and finalised test scenarios
    [button_manager.cpp, config.h, main.cpp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]
2026-02-06 Updated calibration and OTA URL
2026-02-06 Added loading calibration data from NVS
2026-02-06 Fixed button logic in sleep mode
    [button_manager.cpp, main.cpp]
2026-05-06 bump: v1.1.0 — Phase auto-detection
2026-05-06 bump: v1.2.0 — Phase auto-detection
2026-05-07 add phase filter
